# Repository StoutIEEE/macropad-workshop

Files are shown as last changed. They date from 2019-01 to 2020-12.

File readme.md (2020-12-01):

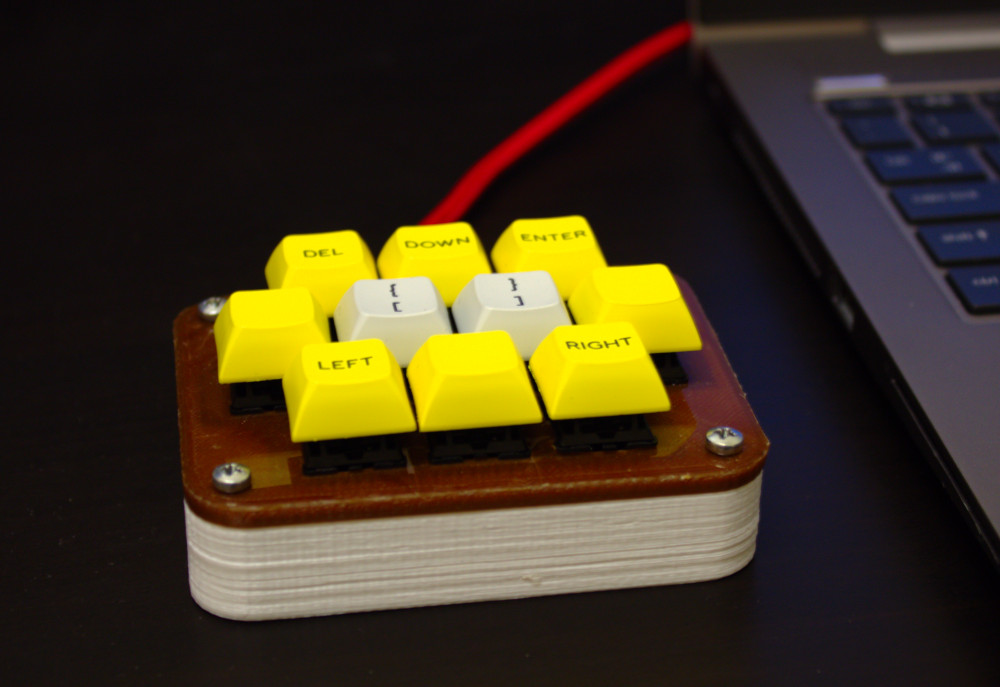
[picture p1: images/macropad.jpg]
Final Project


# Macropad workshop

This is the repo for everything related to the IEEE macropad workshop (aside from the firmware, and keymaps which can be found in the [QMK firmware repo]())

A BOM, the circuit, and casing files can be found here as well as instructions to build.

## Instructions

1. [Start](start.md)
2. [Prep](prep.md)
3. [soldering](soldering.md)
4. [Testing and build wrap up](test-wrapup.md)
5. [Programming](programming.md)
  * [Single layer](single-layer.md)
  * [Multi layer](multi-layer.nd)
  * [Compiling](compiling.md)
6. [End](end.md)

## Special thanks to...

##### Professor Steven Heidtke
 + Helping us CNC mill our base parts
 + Spending ***a lot of time*** with us to get the milling code working

##### Fryklund Lab 101
 + Providing us a big scary CNC machine to make parts with

##### Melissa @ PimpMyKeyboard
 + Helping us get our keycaps in order

##### Will @ SwitchTOP
 + Helping us get our keyswitches in order

##### IEEE Twin Cities
 + Helping us out with funding for the workshop

##### Stout Student Association
 + Helping us out with funding for the workshop
 + Putting up with our shenanigan

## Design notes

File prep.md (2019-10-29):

# Prep

## The casing

Before we start on anything else we should start with the casing. Start by getting the switches installed in the plate. Popping the switches in is easy and shouldn’t take you too long. Make sure all switches face the same direction. The photo below is shot from the long side of the plate. The correct orientation for the switch is as shown. The holes in the cut out portion of the switches should be parallel with the long sides.

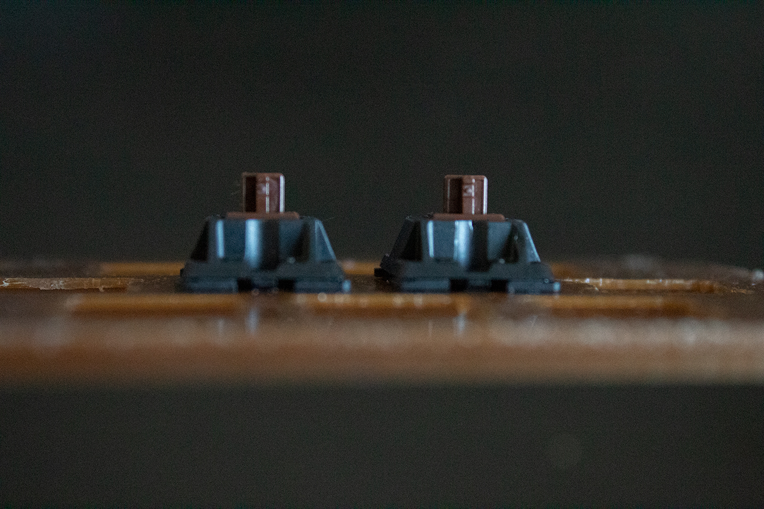
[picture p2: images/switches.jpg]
switches


The plate we’re putting the switches on is 3d printed, so if when you put the switches in they look like the switches do below you will need to clean the hole out. We have sandpaper and x-acto knives for this purpose. Make sure to not remove too much from the plate. The switches should have a snug fit.

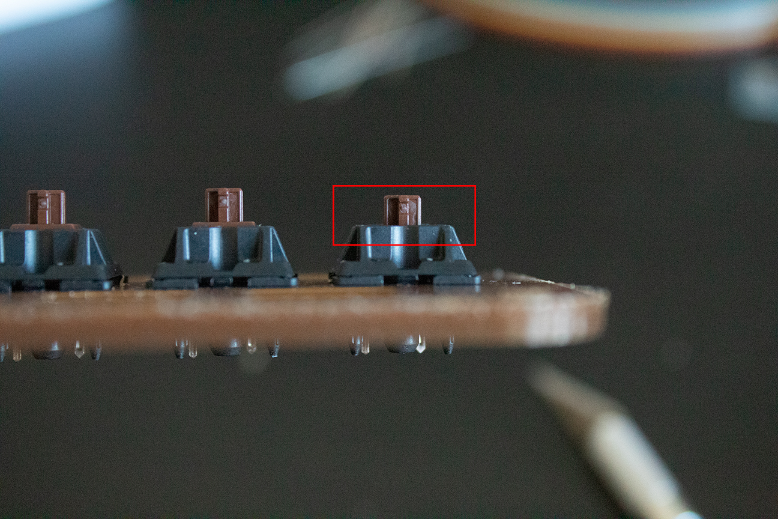
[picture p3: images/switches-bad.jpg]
bad switches


## The compile environment

First you need a text editor. I recommend [atom](https://atom.io/) and my examples in the workshop will use it and all directions will assume you are. Augment the directions for your preferred text editor if you would like to use something else.

Setting up the build environment differs based on what system you're on. Following the guide [here](https://docs.qmk.fm/#/newbs_getting_started) can get you all set up. You should download the x86_64 version.
We'll walk through what the guide says for **Windows** below with screenshots.

If you are on another system, this will be slightly easier.

***Note:*** If you have the windows subsystem you *could* follow the Linux instructions from the bash terminal. You will have to manually flash your board though and I ***HIGHLY*** recommend you don't. Using avrdude is out of the scope of this workshop.

#### Windows:

To start, download msys2. That can be found [here](http://www.msys2.org/). You want to click the middle download button (for x86_64).
Allow it to install and open it (just leave the last box checked).
Once it opens paste this command in:

`sh -c "$(curl -fsSL https://raw.githubusercontent.com/StoutIEEE/macropad-workshop/master/setup-qmk.sh)"`

It will ask you to say yes a lot. Just type `y` in response. If it **doesn't** ask you a yes or no question, use your best judgement. We want whatever the default option is or the "all" option for simplicity. A few examples are shown below.

example1

example2

At one point it will ask you for administrative privileges, just say yes. *I promise nothing bad will happen.* It needs to install drivers for the AVR and ARM microprocessors.

Once the whole process finishes, close the window and relaunch msys2. This script will prompt you.

Enter this command to get into the source code folder: `cd ~/qmk_firmware/`

We're done setting up our built environment. [***Now it's time for the real magic.***](soldering.md)

#### Linux and Mac:

**Note**: Only Debian, Ubuntu, Fedora, and Arch are supported Linux distros. The script will probably still work if you have git installed and are on another distro.

Open your terminal. For macs this will be in your app launcher or in your apps folder under utils. You could also search for terminal with `CMD+Spacebar`

Paste in this command: `sh -c "$(curl -fsSL https://raw.githubusercontent.com/StoutIEEE/macropad-workshop/master/setup-qmk.sh)"`

This process will vary GREATLY between distros and between Mac and Linux systems. Try to use your best judgment and go with defaults for everything you can.

Once the whole process finishes, close the window and relaunch your terminal. This script will prompt you.

Enter this command to get into the source code folder: `cd ~/qmk_firmware/`

We're done setting up our built environment. [***Now it's time for the real magic.***](soldering.md)

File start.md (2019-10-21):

## The basics - D1

Before we get started, I feel like it's important to go over the basics of how keyboards in general work, and how QMK, the firmware we'll be using for our macropad, works.

### On the subject of hardware

Keyboards use microprocessors from either the AVR or ARM families to read the keyswitches and send pressed keys to the computer. A lot of these chips don't have nearly enough inputs to read just one button with each pin. So keyboards utilize a matrix.

matrix gif (from pcbheaven.com)

In the gif above you can see how this works in a visual way. The microprocessor sends a high signal to each of the columns and checks each row to see if it can see that signal. If it does, that would signal that a key at that position in the matrix is pressed.  

Directly wiring like that brings about a few challenges though. Most notably, there are situations where current could travel where it shouldn't if multiple keys were pressed and can create "ghosting". This can be fixed by inserting diodes in between each button and the input rows, to keep the current from flowing "backwards" and keys from being read when they shouldn't be.

Though the wiring and reading is fundamental to how a keyboard can work, it's useless without something to read! This is where our keyswitches come in. There are quite a few different kinds of keyswitches that can be used. There are really two kinds of switches, purely mechanical switches and membrane switches. Membrane switches are typically associated with cheaper keyboards. There are a few exceptions to this, but we won't go too much into this type since we won't be using it in the workshop. Which leaves us with mechanical switches. There are quite a few different sub-mechanical switch types. The most popular of these switches are the Cherry MX switches and their clones.

cherry diagram

They use a spring to hold up a plastic piece with a set resistance of X grams to separate the contacts that would complete the circuit. Various aspects of the resistance the spring provides, travel time, and the sound it makes very based on the color of the switch. For this workshop we are using a cherry clone made by Gateron that are brown switches. These are quiet (they don't make loud clicking), and are fairly low resistance (45g).

There are other really cool types of mechanical switches like ALPS and buckling switches! We won't go over them, but I recommend learning about them if you choose to explore building mechanical keyboards outside of this workshop!

Finally for our hardware, we need keycaps. These can have different side profiles. From the company we ordered our keycaps from, they have 3 different profiles DSA, SA, and DCS. These really just change how the keys contour on the keyboard (as you can see below).

#### DSC

#### DSA

#### SA


We have all of these for the workshop in bins, so feel free to take a look at them in person when you are picking out your keys for your macropad!

### On the subject of software

For this workshop, we are using the open-source keyboard firmware QMK. It has a lot of neat features and convenience scripts to keep the layman out of the lower level C and assembly weeds. Many DIY keyboards use this firmware such as the Plank, or Ergodox keyboards. One of its neat features is its layer system. Below you can see a diagram of it from their wiki:

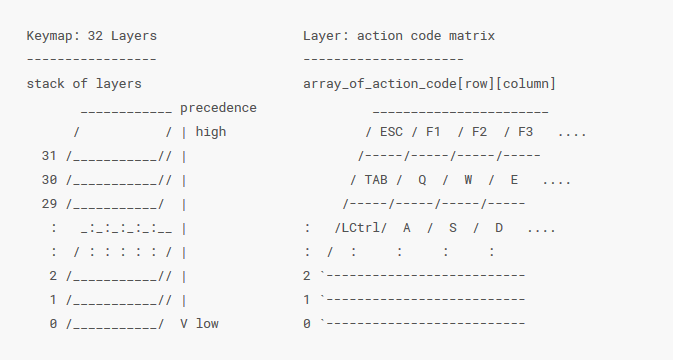
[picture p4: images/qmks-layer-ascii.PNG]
layer diagram (From qmk.fm)


Each layer can have a different keycode for the same position on the matrix. The firmware searches each layer from highest to lowest until it finds what the key should be given the layer it's on. In the keymap, you can have transparent keys to allow lower layers to pass through as you go up. You can switch between layers in a variety of different ways.

Aside from the layers there are other features that allow you to control RGB leds, "tap dance", play sound, etc. For all features, look at their [reference section](https://docs.qmk.fm/#/) in their wiki!

Alright, with that out of the way, [lets move on to the workshop](prep.md)

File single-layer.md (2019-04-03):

# Single layer

Making a single layer keymap is easy enough, start by copying the `simple-numbpad` folder in the keymaps folder and naming it either your moniker or name.

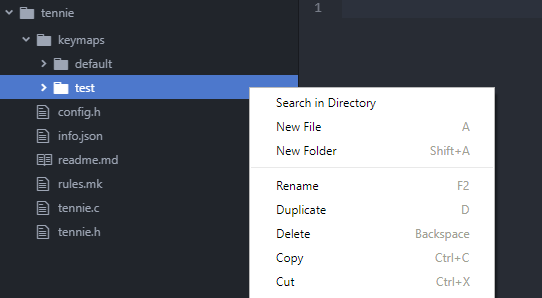
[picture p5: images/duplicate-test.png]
new folder


naming

You'll notice there are 3 files in this folder. We'll start by modifying the `keymap.c` file. Open your file, and turn your attention to the `KEYMAP()` function. This is where you will put the key bindings you want. Basic keys can be put in easily enough. You can find a list of all available basic keys [here.](https://docs.qmk.fm/#/keycodes_basic)

For this example, we'll make our top three buttons song management buttons (skip, play/pause, and previous). Feel free to use whatever keys you would like, I highly recommend looking at the list before continuing. Looking at the [list of basic keycodes](https://docs.qmk.fm/#/keycodes_basic) we can use `KC_MPLY, KC_MPRV` and `KC_MNXT` for play/pause, previous, and next respectivly. You may have noticed that there are also longer names like `KC_MEDIA_NEXT_TRACK` for `KC_MNXT`. Though you could use these longer names, I recommend you don't. The shorter 4 character names layer will fit the little ascii drawing version of the macropad, and it will likely be more readable as a result. I won't stop you if you would prefer less archaic variable names!

If you are following my example, after replacing the top 3 buttons, you should have a key map similar to this.

```
#include QMK_KEYBOARD_H

// Custom keycode definitions, and keycode renames
#define KC_oooo KC_TRNS
#define KC_XXXX KC_NO

// Layer names
#define base  0

const uint16_t PROGMEM keymaps[][MATRIX_ROWS][MATRIX_COLS] = {
  [base] = LAYOUT(
  //         ┌────────┬────────┬────────┐

               KC_MPRV, KC_MPLY, KC_MNXT,

  //    ├────────┼────────┼────────┼────────┼

          KC_4   ,  KC_5  ,  KC_6  ,  KC_7  ,

  //    ├────────┼────────┼────────┼────────┼

                KC_8  ,  KC_9  ,  KC_0

  //         └────────┴────────┴────────┘
  ),
};
```

Now, maybe you also want a key that presses a few keys down at once, like `ALT+F4` or `CTRL+ALT+DELETE`. We will go over that next. For reference you may want to look over [the list of functions](https://docs.qmk.fm/#/feature_advanced_keycodes) you can use. There are a lot of interesting features you can use to make the keyboard do what you want. We'll keep it simple and just use the [modifier keys section.](https://docs.qmk.fm/#/feature_advanced_keycodes?id=modifier-keys). Lets make out bottom keys copy, cut, and paste. Looking at the list of modifier key function, we want to use `LALT(kc)`, so we would need `LALT(KC_C)` `LALT(KC_X)` and `KC_V` for copy, cut, and paste respectivly. These will work, but we want to keep our names at 4 characters! To make them like the simple keycodes we need to make a macro. To do that we write something like this `#define KC_ACPY LALT(KC_C)` at the top of our `keymap.c` file where `KC_ACPY` is our ***unique*** keycode name starting with `KC_` and `LATL(KC_C)` is what we want the keycode to be or do (for this example left alt + C). Doing it for all three we get something like below.

```
#include QMK_KEYBOARD_H

// Custom keycode definitions, and keycode renames
#define KC_oooo KC_TRNS
#define KC_XXXX KC_NO

#define KC_ACPY LALT(KC_C)
#define KC_APST LALT(KC_V)
#define KC_ACUT LALT(KC_X)

```

We can then use our new keycodes we made in our keymap! We'll put them at the bottom of our macropad.  The end result should look something like this.

```
#include QMK_KEYBOARD_H

// Custom keycode definitions, and keycode renames
#define KC_oooo KC_TRNS
#define KC_XXXX KC_NO

#define KC_ACPY LALT(KC_C)
#define KC_APST LALT(KC_V)
#define KC_ACUT LALT(KC_X)

// Layer names
#define base  0

const uint16_t PROGMEM keymaps[][MATRIX_ROWS][MATRIX_COLS] = {
  [base] = LAYOUT(
  //         ┌────────┬────────┬────────┐

               KC_MPRV, KC_MPLY, KC_MNXT,

  //    ├────────┼────────┼────────┼────────┼

            KC_4 ,  KC_5  ,  KC_6  ,  KC_7  ,

  //    ├────────┼────────┼────────┼────────┼

               KC_ACUT, KC_ACPY, KC_APST

  //         └────────┴────────┴────────┘
  ),
};
```

[Now you're ready to compile!](compiling.md)

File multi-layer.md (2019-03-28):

# Multi-layer

Multi-layered set ups are a bit more difficult but much more fun to program and allow for much more keys to be mapped! I'm going to assume you feel at least a little comfortable with C or C++ and are willing to dig in a bit more to the QMK documentation.

 To make a multi-layered keymap lets start by copying a template. The `default` keymap should be used. Copy the folder and rename it to your name or online moniker.

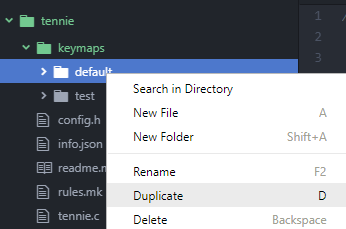
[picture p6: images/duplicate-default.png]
new folder


naming

You'll notice there are 3 files in this folder. We'll start by modifying the `keymap.c` file. Open your file, and turn your attention to the `KEYMAP()` functions, and the macros above it.

I'll start by explaining the example.
```
// Layer names
#define base  0
#define shrek 1
#define ogre  2
#define tcp   3

// Layer Switches
#define KC_SHRK TT(shrek)
#define KC_OGRE TT(ogre)
#define KC_TCP TT(tcp)
```

Each layer is a 2 dimensional array, in another array. We can work with just indexes from 0 to 31 for that 3rd array of keymaps, but it's much easier to remember both the functionality and to deal with if you give each index a name. Remember when laying these out that the firmware will seek the keycode from highest layer to lowest. If you wanted to use a key from one layer, it should be beneath the layers you want it on!

The second part there with `#define KC_SHRK TT(shrek)` are layer switch keycode macros. There are a few different functions you could use that would toggle layers in different ways. Those can be found [here in the layers section.](https://docs.qmk.fm/#/feature_advanced_keycodes) The KC_* is just a nice shorthand for the keymaps to be more readable when it's put in the layout. I recommend reading the whole section, and [the basic keycodes section](https://docs.qmk.fm/#/keycodes_basic) before moving on.

After that, you have the 3d array of keycodes.

Each layer looks something like this:
```
[base] = LAYOUT(
//         ┌────────┬────────┬────────┐

              KC_X  ,  KC_X  ,  KC_X  ,

//    ├────────┼────────┼────────┼────────┼

         KC_X  ,  KC_X  ,  KC_X  ,  KC_X  ,

//    ├────────┼────────┼────────┼────────┼

              KC_X  ,  KC_X  ,  KC_X

//         └────────┴────────┴────────┘
),
```

You would replace KC_X with whatever basic or advanced keycode you would desire. You would use transparent keys in a layer to allow the lower layer to bleed through. You can also have a KC_NO or KC_XXXX to block out a key from being read on a layer. When making your layers, keep in mind.

For all advanced keycodes, I recommend a macro like the layer macros to keep the `LAYOUT`s clean looking. I also recommend the shorter no-more-than-4 names for keycodes, and macros.

Good luck! If you want any help come grab me (Jack Hildebrandt), I'm always happy to help!

[After you get everything squared away, you should move on to compiling.](compiling.md)

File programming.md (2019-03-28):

# Programing

Now that you have a working keyboard, you can customize it to make it work the way you want. We'll be around to help you, but it's your keyboard so it's impossible to write up a guide for what you'd want! We can however write a guide for the process.

To start open a text editor. Again, I recommend [atom](https://atom.io/) and my example will use it and all directions will assume you are. Augment the directions for your preferred text editor.

To start, open your text editor. If you just installed atom, you will have a few welcome files to close. Open the folder qmk folder. That will be:
+ `C:\msys2\home\<username>\qmk_firmware\keyboards\handwired\tennie\keymaps\` for Windows with msys2
+ `/Users/<username>/qmk_firmware/keyboards/handwired/tennie/keymaps/` on Mac
+ `/home/<username>/qmk_firmware/keyboards/handwired/tennie/keymaps/` on Linux

In atom this can be done through `File > Add Project Folder...` and navigating to that folder.

You should have a dropdown with folders on the left hand of your screen containing these two folders.

project image

At this point you have a decision. **You must choose if you want a single layer or multiple layers.** Having multiple layers will allow you to have more keys bound to a single key and will have more functionality but will be more complicated to set up and remember. I ***strongly*** recommend going with the single layer unless you feel comfortable with C or C++ and are willing to get into the documentation weeds and figure some things out.

+ [Directions for single layer](single-layer.md)
+ [Directions for multiple layers](multi-layer.md)

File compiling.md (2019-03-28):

# Compiling

To compile your firmware, you run a similar command to how we tested our environment.
`make handwired/tennie:<folder-name>:avrdude` where "folder-name" is what you named the folder you made earlier!

Ideally it will work the same way and will end with you pressing the reset switch through the case. You may however encounter an error. If you do, it will look something like this...

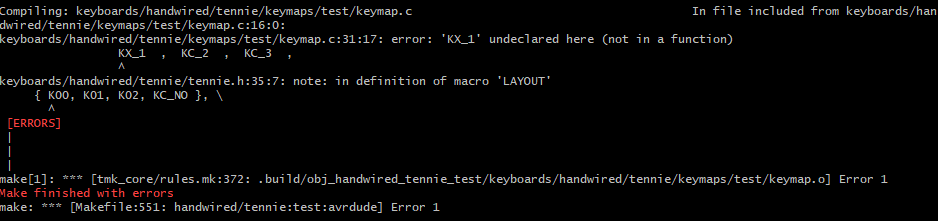
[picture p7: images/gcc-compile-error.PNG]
gcc error


In this example, KC_1 is misspelled. If you do get an error, just try your best to work through it. If you can't figure it out, grab someone who is assisting with the workshop.

If it succeeds, test your macropad. Make sure all the keys do what you think they should. If not, try to correct them in your code. If they do, you're done! Congratulations on completing the Macropad Workshop!

If you wanted to continue or explore more... [look at this](end.md)

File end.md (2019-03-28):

# Continue?
You made the macropad and you're happy with it but maybe you want to learn more and try making a full keyboard.

There's a lot out there to learn. Here are some resources I recommend.

+ [A much better explanation of keyboard matrixes](http://pcbheaven.com/wikipages/How_Key_Matrices_Works/)
+ [A subreddit about mechanical keyboards, they have a lot of information in their wiki and cool keyboards people have built](https://reddit.com/r/MechanicalKeyboards)
+ [The github page for QMK, the firmware we used in this workshop. They have a lot keyboard building information in their wiki](https://github.com/qmk/qmk_firmware)
+ [A place to get custom keycaps (and where we got ours for this workshop)](https://pimpmykeyboard.com/)
+ [A place to get keyswitches (and where we got ours for this workshop)](https://www.switchtop.com/)

Good luck out there!

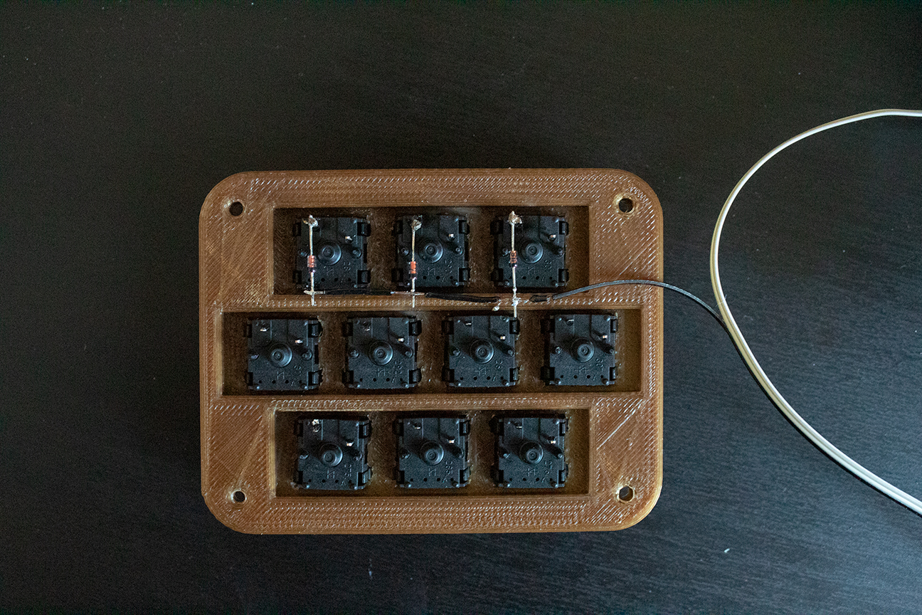
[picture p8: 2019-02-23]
images/rows.jpg

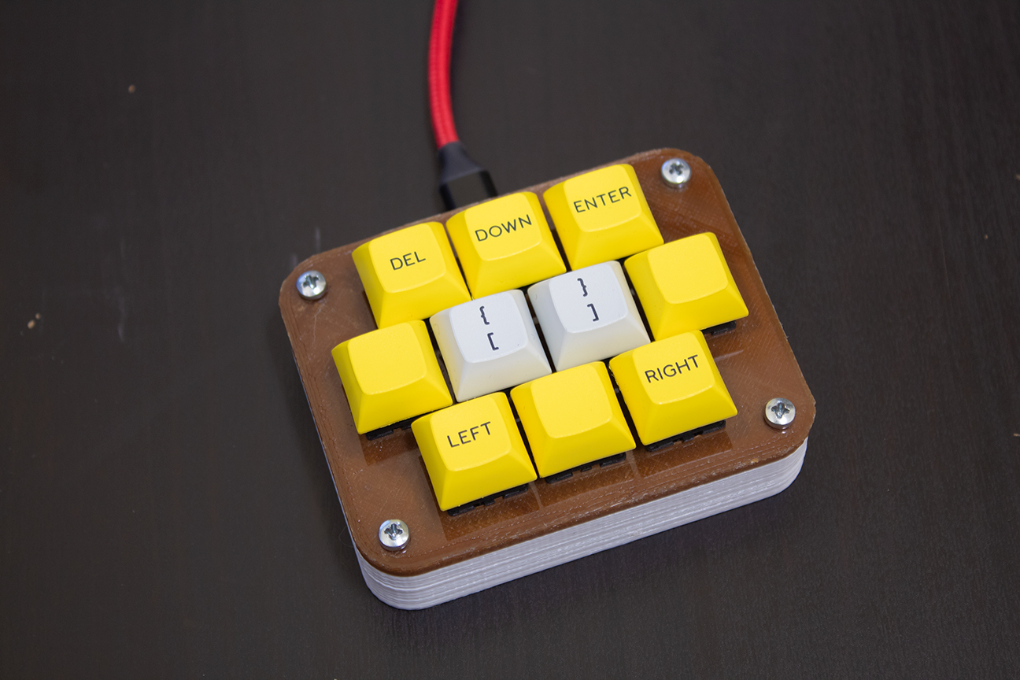
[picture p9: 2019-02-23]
images/another-one.jpg

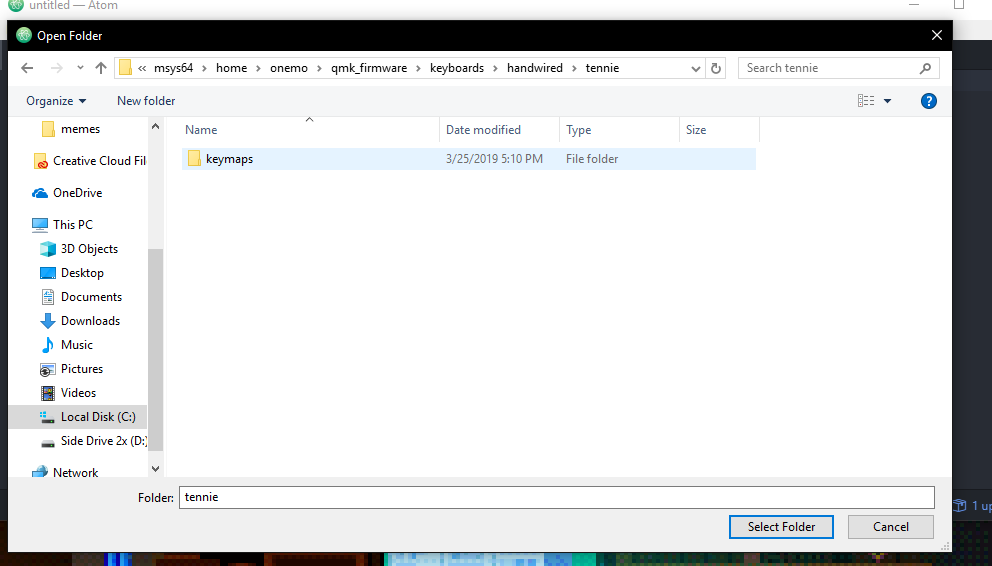
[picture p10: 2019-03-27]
images/open-project.PNG

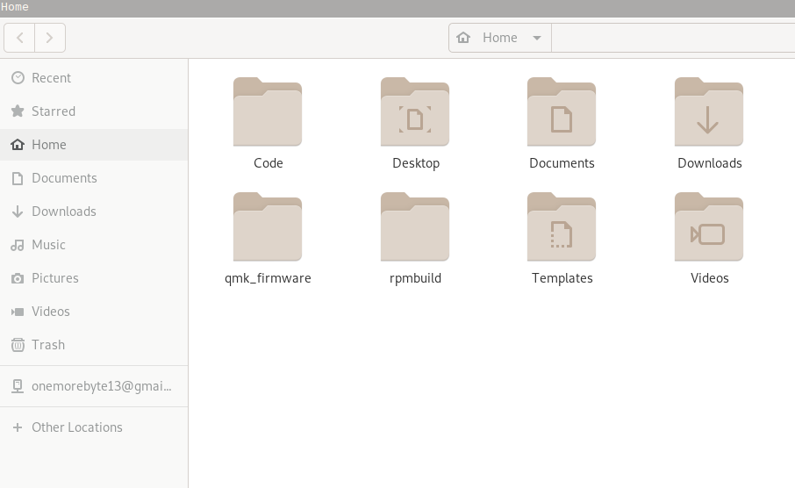
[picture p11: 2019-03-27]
images/linux-location.png

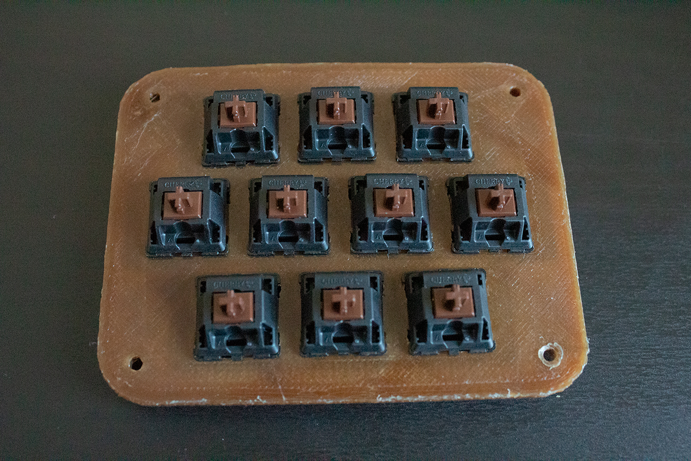
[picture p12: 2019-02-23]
images/switches final.jpg

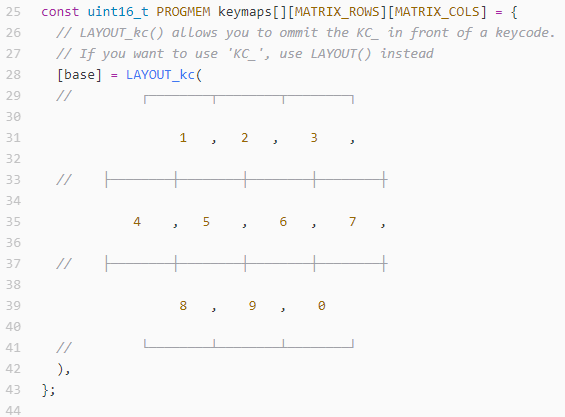
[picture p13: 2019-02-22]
images/keymap.PNG

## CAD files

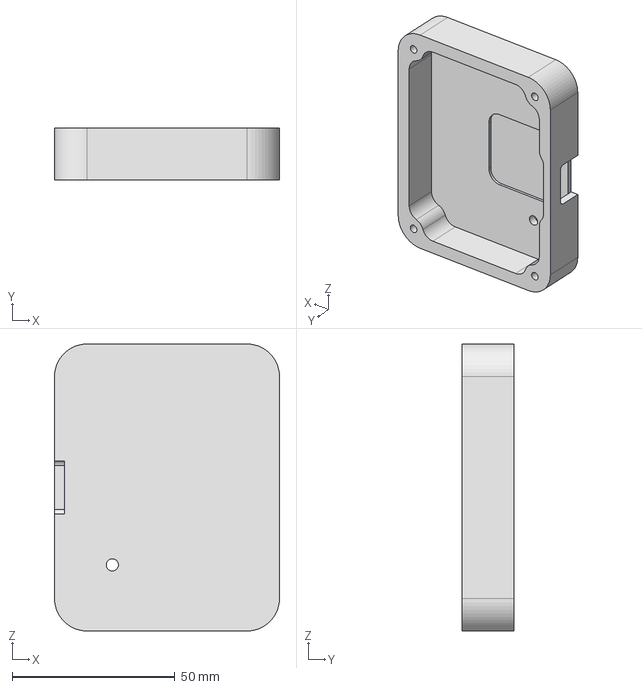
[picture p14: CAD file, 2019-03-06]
case/macropad-frame-v2.stp
69.2 x 16.0 x 88.2 mm

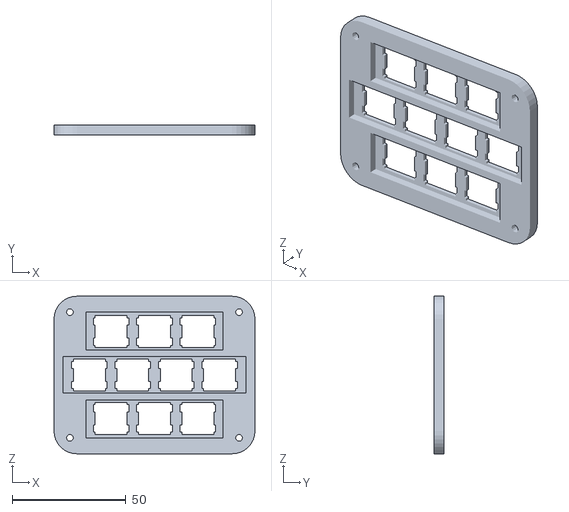
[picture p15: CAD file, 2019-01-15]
case/stl/macropad-plate.stl
88.2 x 4.50 x 69.1

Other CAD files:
case/stl/macropad-frame.stl
case/cad/macropad-frame-v2.ipt
case/cad/macropad-frame.ipt
case/cad/macropad-plate.ipt
case/cad/macropad.iam
case/stl/macropad-frame-v2.stl

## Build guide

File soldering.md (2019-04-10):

# Soldering

## The start

This part will take some time. Please be patient and take your time. We will have some spare supplies if something breaks, but we don't have enough to replace everyone!

The wiring has 4 parts, soldering the diodes, soldering the wires, soldering the additional stuff, and soldering everything to the microcontroller.

**You may want to use this for your reference while soldering the wires and columns. Keep in mind you are wiring and soldering from the bottom, so the wiring will be flipped horizontally**
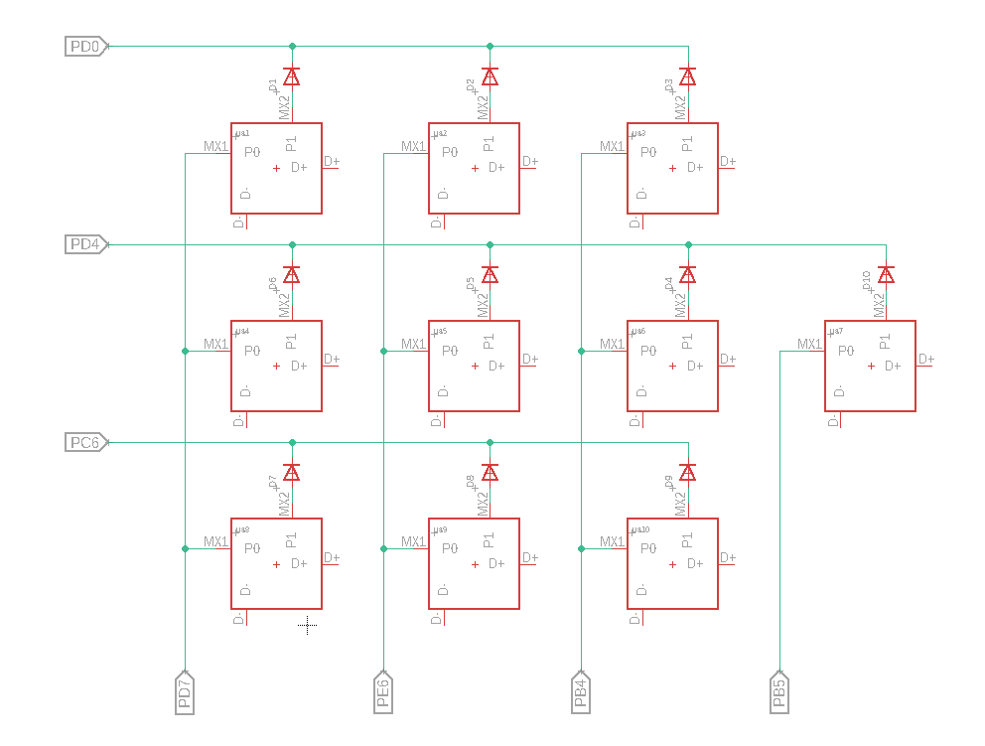
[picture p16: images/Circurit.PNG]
Diagram


### The diodes

Soldering the diodes can be a bit tricky without a lot of extra help. Personally I have found success in bending the diodes like so....

#### **Take special care to make sure that the black part matches up with the picture. Diodes have an orientation and won't work in reverse**

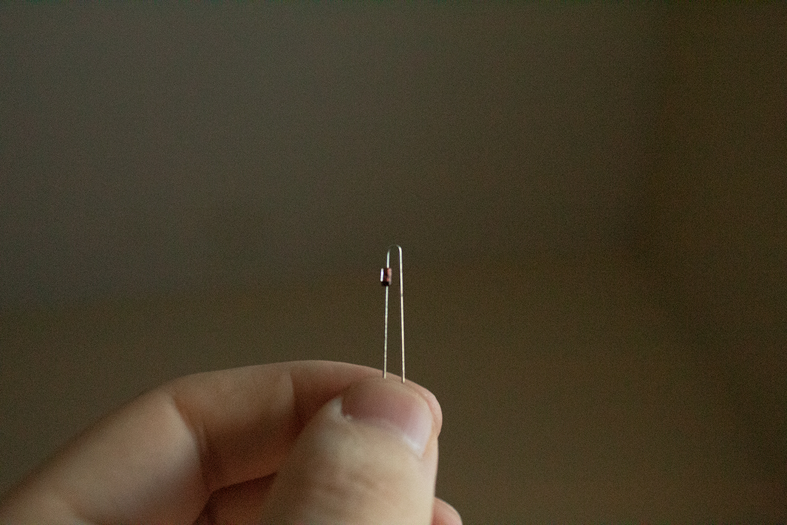
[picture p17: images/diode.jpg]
diode bend


With the diodes bent like that, you can use the extra bent wire part as a stand. You should be able to get it to balance against the plastic numbs on the switches. Work in rows, and use a wire snips to get rid of the extra leg portion. Leave a little space beyond the switch. It shouldn't stray into the next row, **but you also want a lot of room for soldering the wires in the next step**!

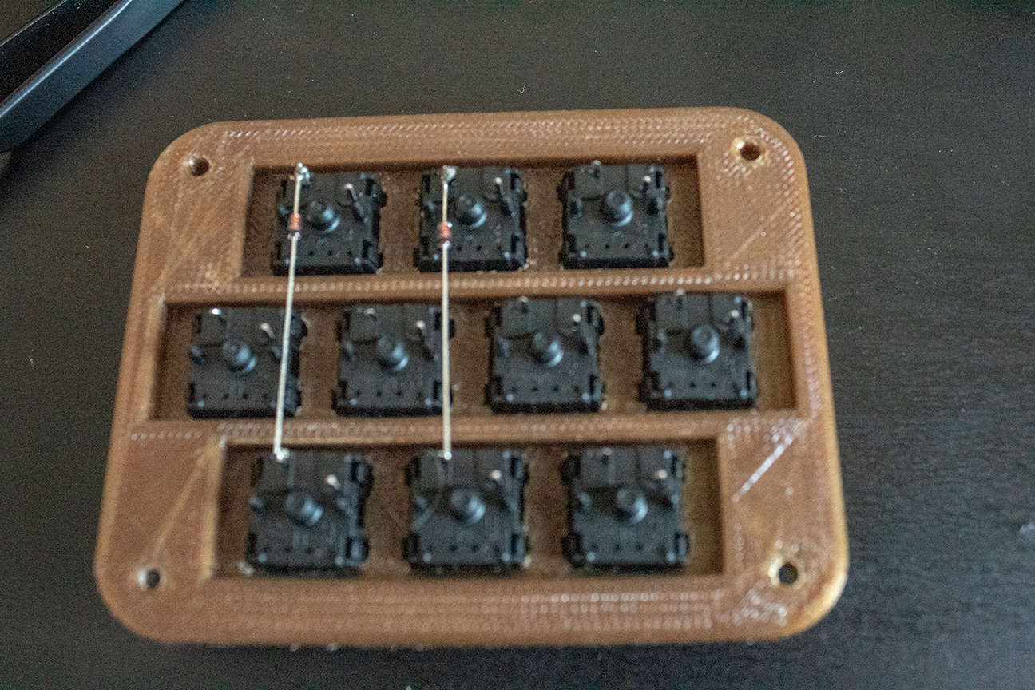
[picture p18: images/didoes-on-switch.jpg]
diodes soldered


When they are all soldered and snipped it's time to move on to soldering the wires!

### The wires

##### I want to start off by noting that I only have one row of diodes in the first picture. You should have a full macropad's worth.
<br>
 To start off, we'll solder the rows. Separate three of the wire colors from the provided wire. Keeping them as together as possible, separate them at the end. This can be done easily with either a wire snip tool or an exact-o knife. You want them to stay together in the middle for wire routing. To take it a step further, you may get a cleaner look if you measure out the length before pulling each off.

 After you have the wire split, you need to strip it. There are two ways to go about this you can either strip it in three to four places, or you can strip it the full length and use electrical tape to cover where wires will overlap. I recommend the electrical tape method for simplicity, though partially stripping it will be cleaner looking.

  The wires will lie along the diodes you just soldered. In the below pictures you may be able to see how this will end up looking. There is a picture showing both methods. After matching up the position of the exposed wire, you will want to tin the wire and diodes. This will make the soldering easier. Then just go through and make sure all the diodes are connected to your wire.

#### The end result should look something like this.

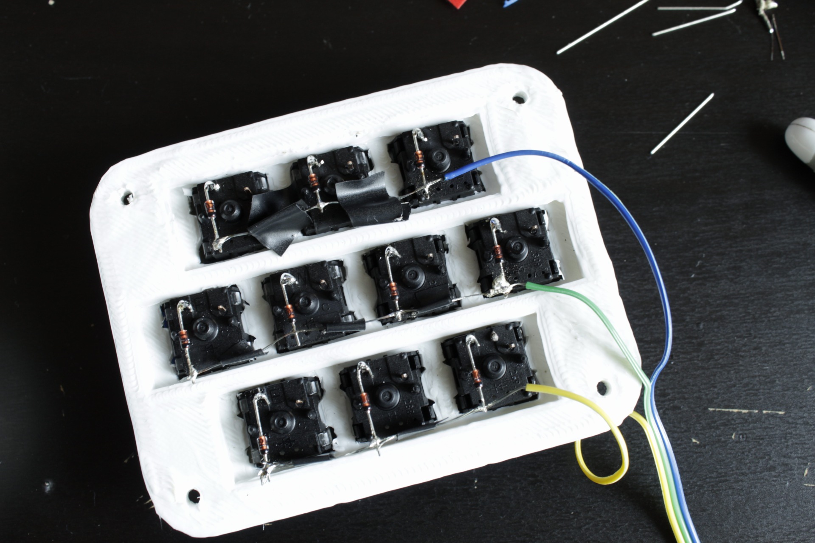
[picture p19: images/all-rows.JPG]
all rows


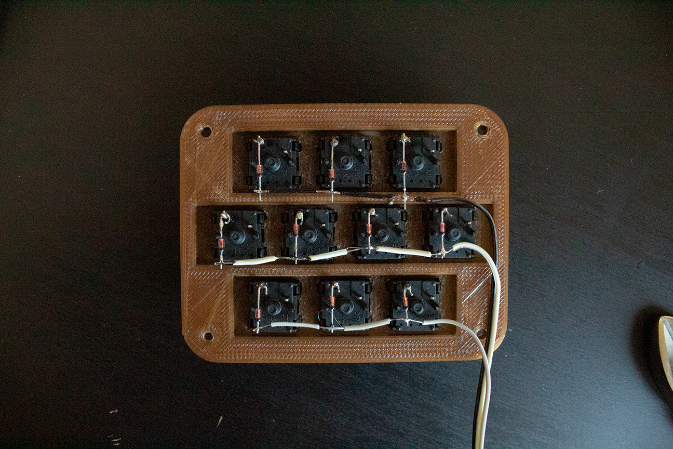
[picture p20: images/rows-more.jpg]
all rows


After completing the rows it's time for the columns. **This is where order matters to an extent.** You need to make sure you match what is pictured, because one of the columns is missing two switches. The firmware will need to be changed if it differs from what is shown, and your macropad won't work right away!

Separate 4 more colors off the wire you are given.

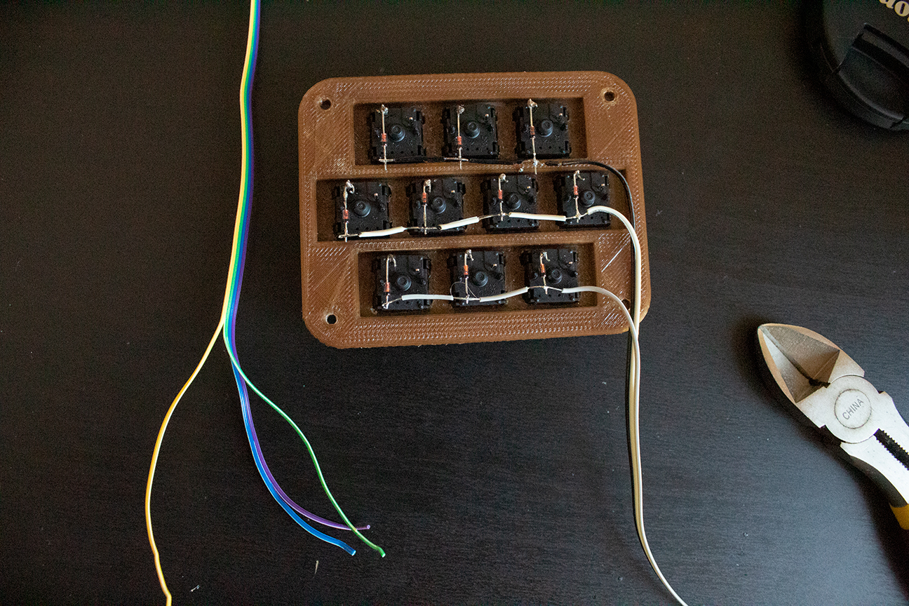
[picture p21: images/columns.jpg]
columns


This will be a similar process to what you did for the rows, except now we are soldering vertically instead of horizontally and we will be soldering directly to the switch. Solder the wires like shown below.

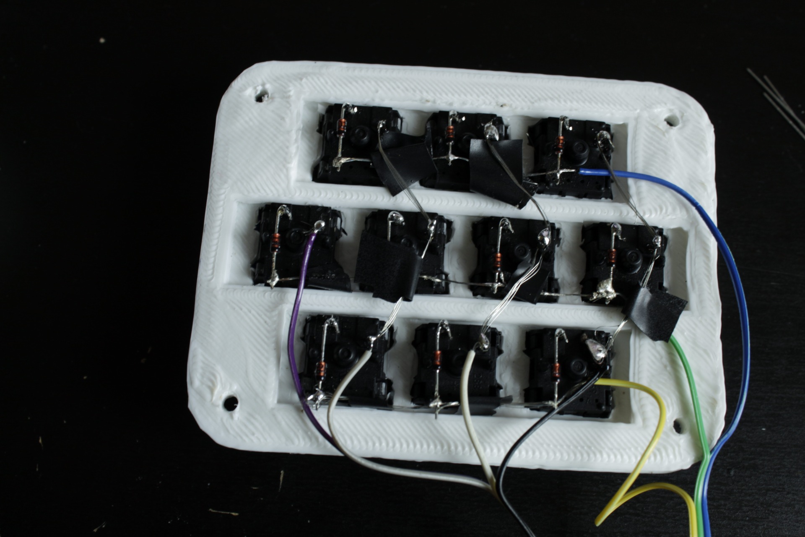
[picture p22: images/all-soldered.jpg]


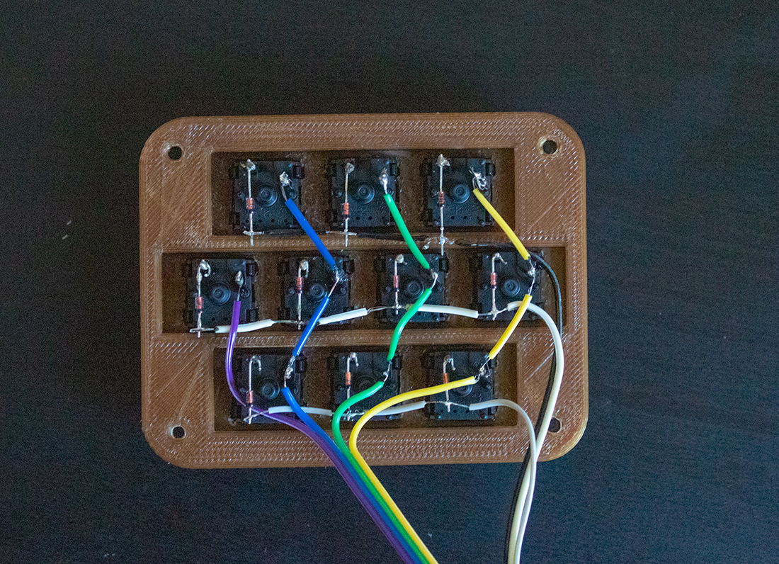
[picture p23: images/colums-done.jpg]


After you wrap this up you are done with the hardest part! (soldering wise)

### The microcontroller

Again order matters a lot here. Below is a pinout of the microcontroller.

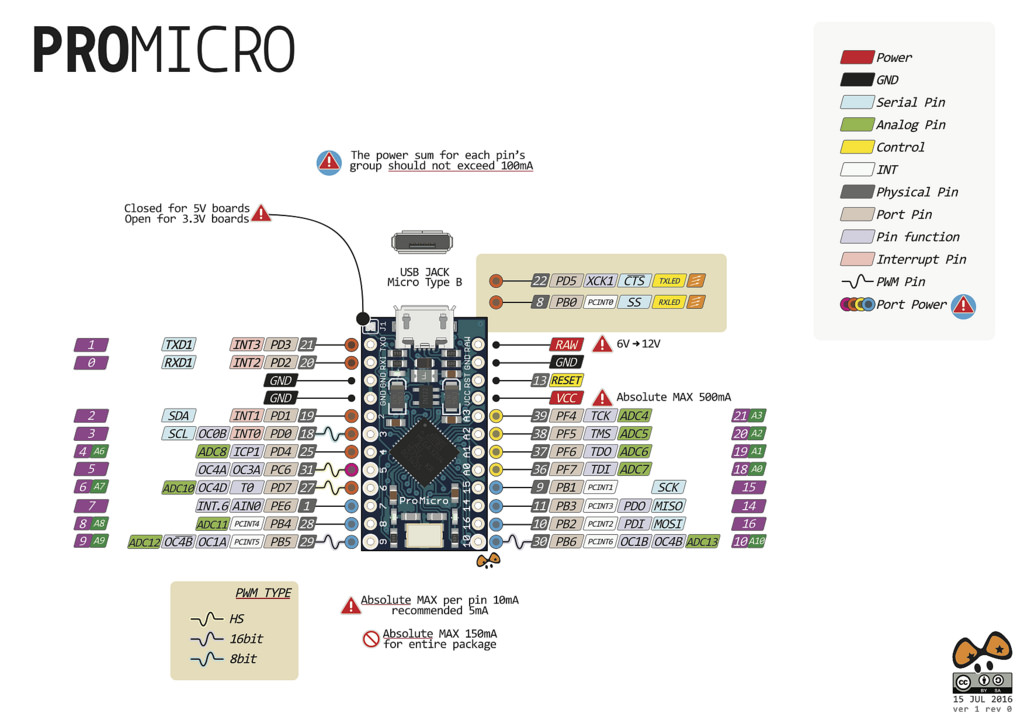
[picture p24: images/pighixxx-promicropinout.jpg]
Microcontroller pinout


You shouldn't need this unless you did something weird soldering up to this point, but it's a nice reference to have!

If you have the macropad in front of you like it's shown in the pictures, the wires should be soldered to the pins like so...

```
ROWS:
 bottom -> Pin #3 (PD0)
 middle -> Pin #4 (PD4)
 top    -> Pin #5 (PC6)

COLUMNS:
 far right    -> Pin #6 (PD7)
 middle right -> Pin #7 (PE7)
 middle left  -> Pin #8 (PB4)
 far left     -> Pin #9 (PB5)
```

Here's an annotated photo as well to help understand locations.

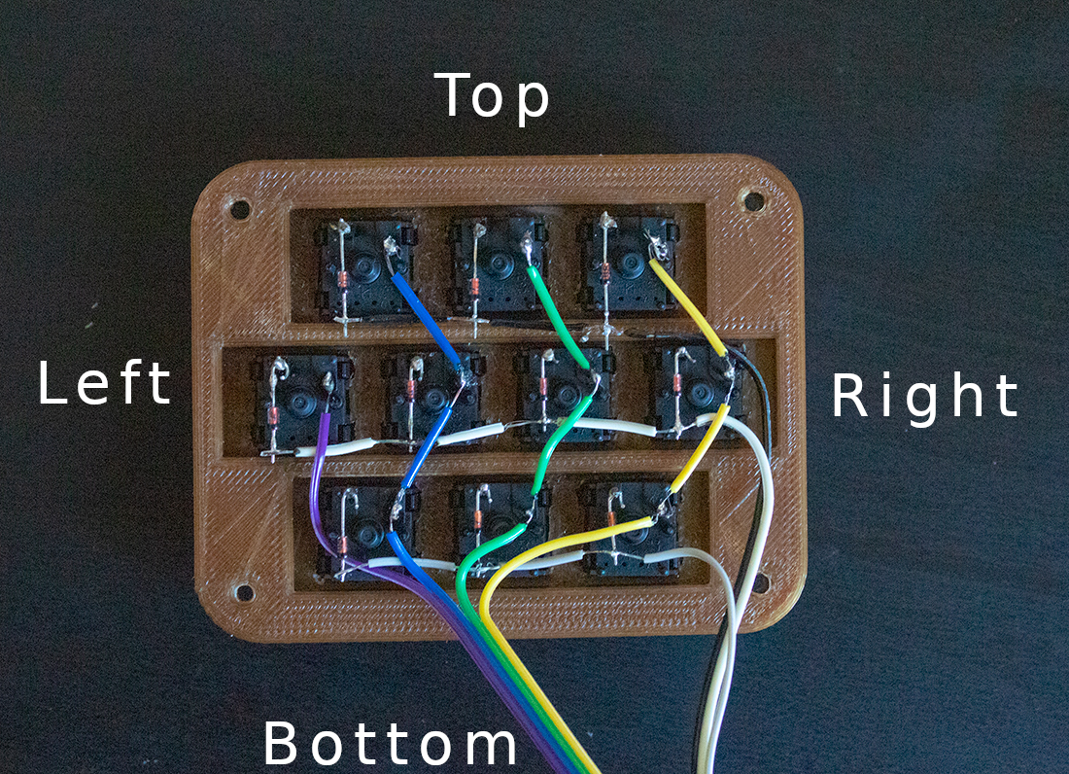
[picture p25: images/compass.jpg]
image of pinouts


Solder the wires to the documented pins. If you kept the wires together, putting them in shouldn't be too much trouble.

You will want to chop off the extra wire you don't need so the wires will fold into the base better when we close it up. For measuring the length you need to save, put the plate above the frame, and measure to the microcontroller footprint in the base. It will also be helpful to pop the microcontroller into it's footprint so you can look at pins too.

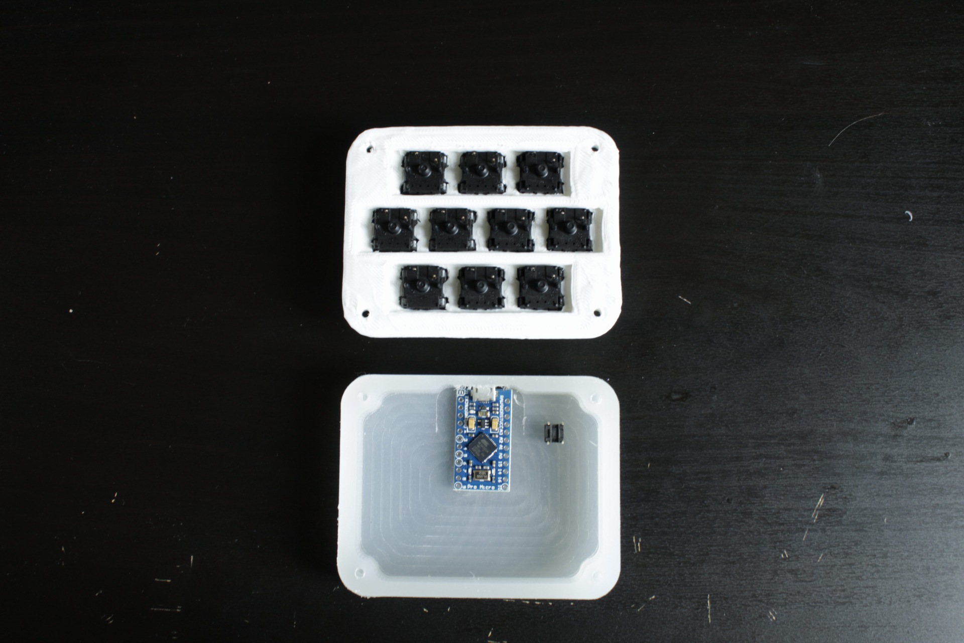
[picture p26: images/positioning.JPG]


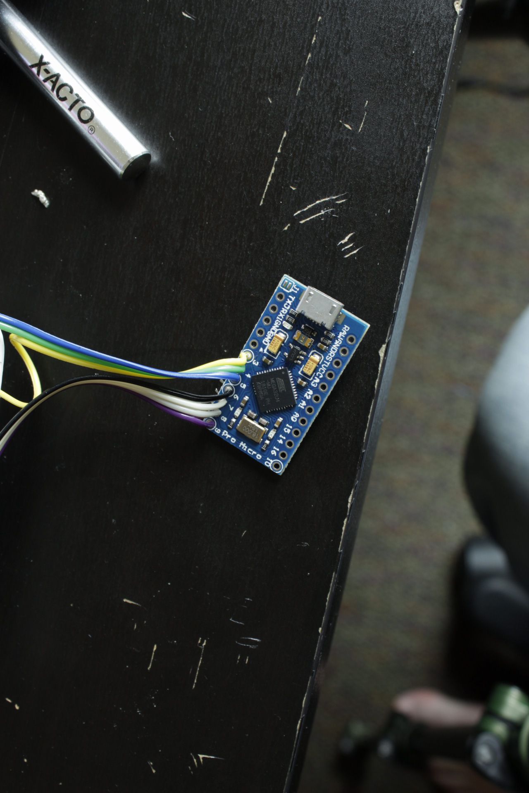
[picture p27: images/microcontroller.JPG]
hole for reset switch and micro


After the rows and columns are soldered, you have all you ***need*** for your macropad to function. We're going to solder an extra thing to make our life easier.

### The reset switch

Now we need to solder the reset switch so we can program the macropad! We don't *necessarily* need it, but it will make programming it easier. Below is an image of where the reset switch will be glued down. (Button in the hole so we can press it without opening the case)

hole for reset switch and micro

Using this information, cut a bit of your unused wire colors to size.

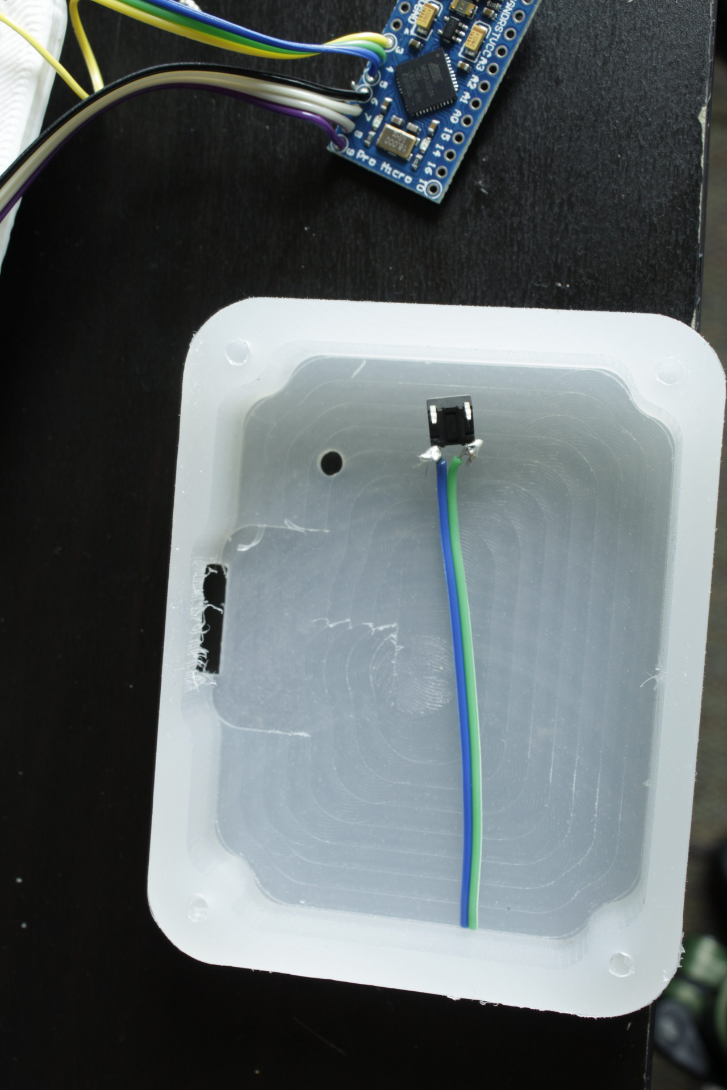
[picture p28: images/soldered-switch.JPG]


Solder them to the RESET and GND pins on the right side of the board. A picture of a finished board is below. These pins are labeled.

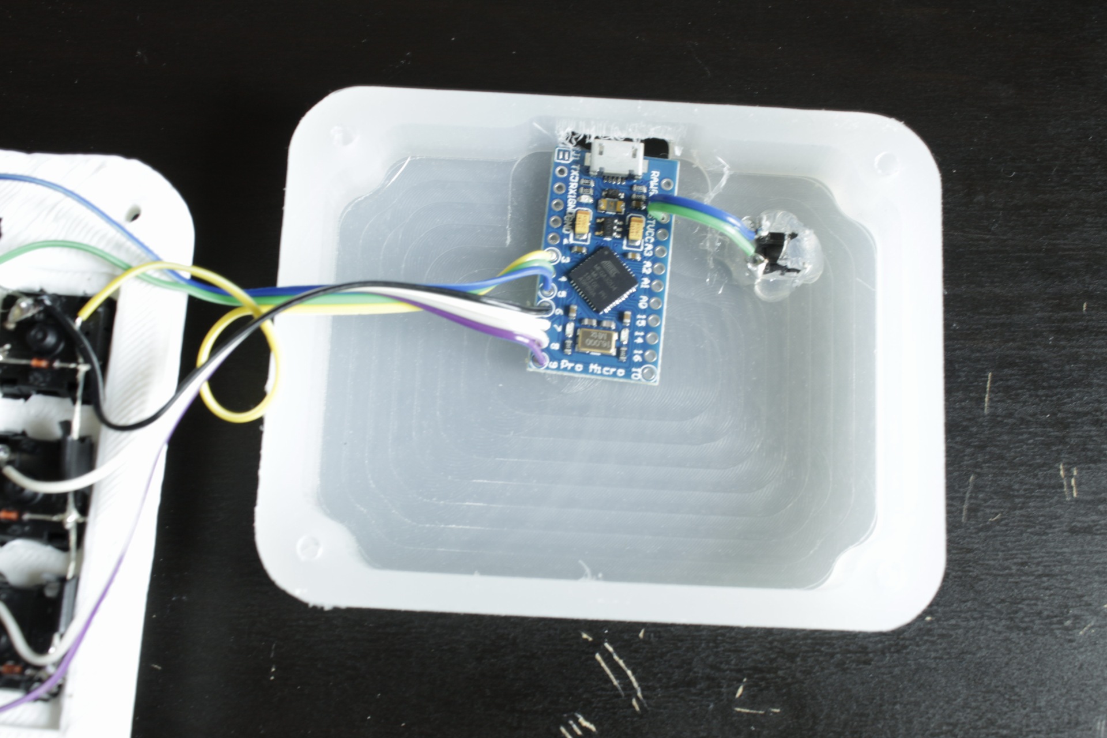
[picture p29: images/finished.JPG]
finished reset switch and board


After you solder that, you're all done with soldering for this workshop!

[Let's move on to testing your soldering work.](test-wrapup.md)

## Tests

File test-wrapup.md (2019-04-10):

# Testing and wrapping up the building

Now that we're ready start playing with our firmware, we need to first test and make sure everything works. Lets start by building against the test layout so we can see if everything is soldered right. Open your terminal and enter `cd ~/qmk-firmware/` in terminal followed by our build command: `make handwired/tennie:simple-numbpad:avrdude`

It will build. When it finishes it will prompt you like below.

avrdude prompt

Press the pushbutton we soldered to ground and reset. It should find your keypad and will start flashing it. When it finishes you should see something like this. If you don't call over one of the workshop helpers.

finished

Now your firmware should be ready to go. Test your keyboard by opening something you can type into. Your keys should match what's below.
```
         ┌────────┬────────┬────────┐

              1   ,   2    ,    3   ,

    ├────────┼────────┼────────┼────────┼

        4    ,    5   ,   6    ,   7    ,

    ├────────┼────────┼────────┼────────┼

              8   ,   9    ,    0

         └────────┴────────┴────────┘
```
If it doesn't, grab an exec or one of the people helping, something's wrong and we will need to troubleshoot.

If it does, congratulations! Your macropad works! now we just need to finalize all the hardware and seal it up. We need to glue down the reset switch and microcontroller. You should have something like below.

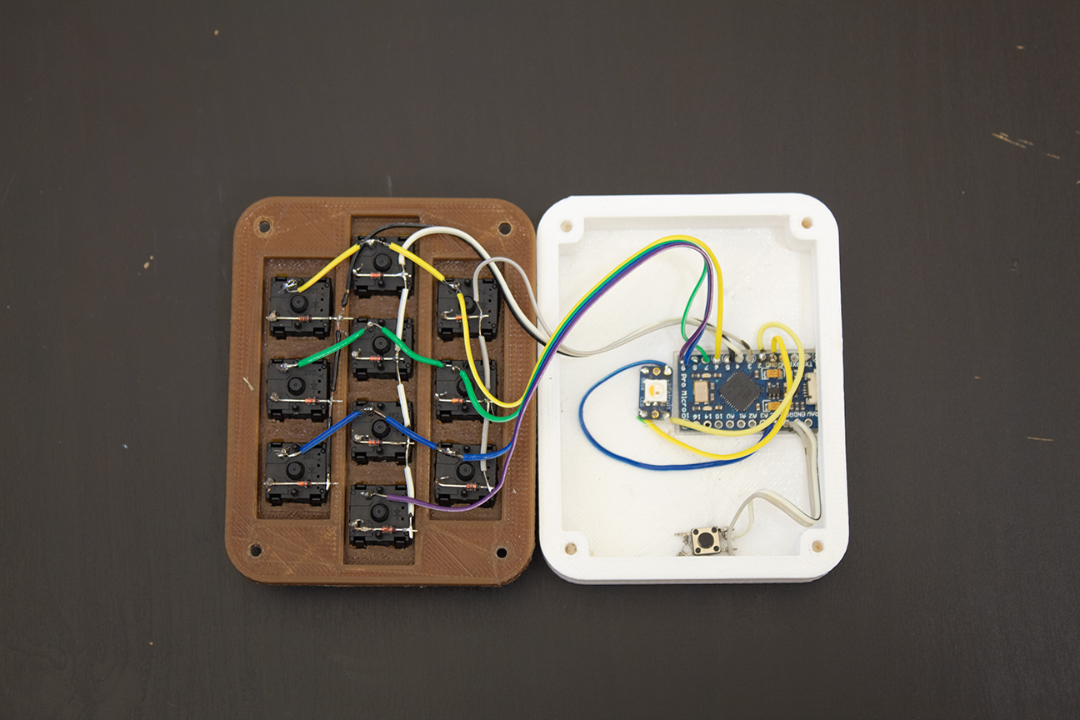
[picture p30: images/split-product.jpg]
split, unclosed


Now, you just need to curl the wires into the frame, and seal it up with the screws!

[Now we can move on to customizing the keys functionality!](programing.md)

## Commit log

2019-02-22 Update parts, Start work on readme, add more pictures
    [Macropad.sch, macropad-frame.ipt, macropad-frame.stl]
2019-03-06 Work on soldering writeup. Make new version of frame for CNC milling.
    [macropad-frame-v2.ipt, macropad-frame-v2.stl, macropad-frame-v2.stp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]
2019-03-28 Finish writeup
    [Macropad.sch]
2019-04-10 Update soldering piece
